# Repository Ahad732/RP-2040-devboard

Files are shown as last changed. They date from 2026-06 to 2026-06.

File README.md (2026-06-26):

# Rp2040 Devboard
I have made a devboard with RP 2040. It has 16 mb storage and its just like a raspberry pi pico but in my design. I had build it off a guide from macondo.I built it to learn hardware. This was my first hardware project for hackclub

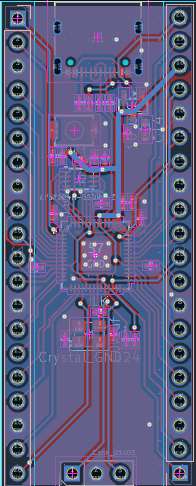
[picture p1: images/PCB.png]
PCB
  
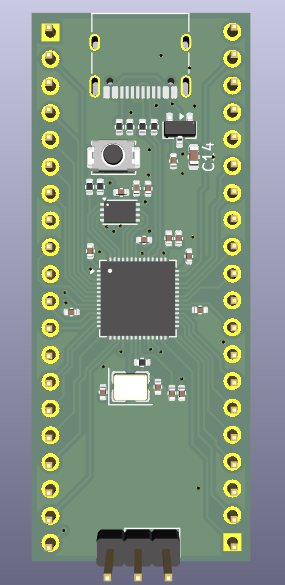
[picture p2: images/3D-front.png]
  
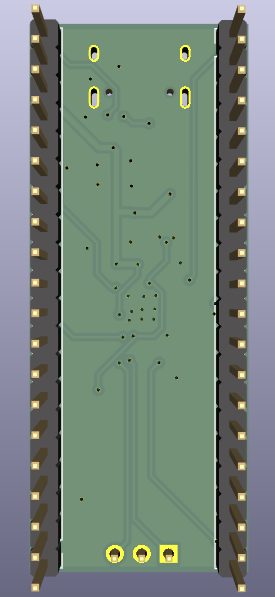
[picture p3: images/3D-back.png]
  
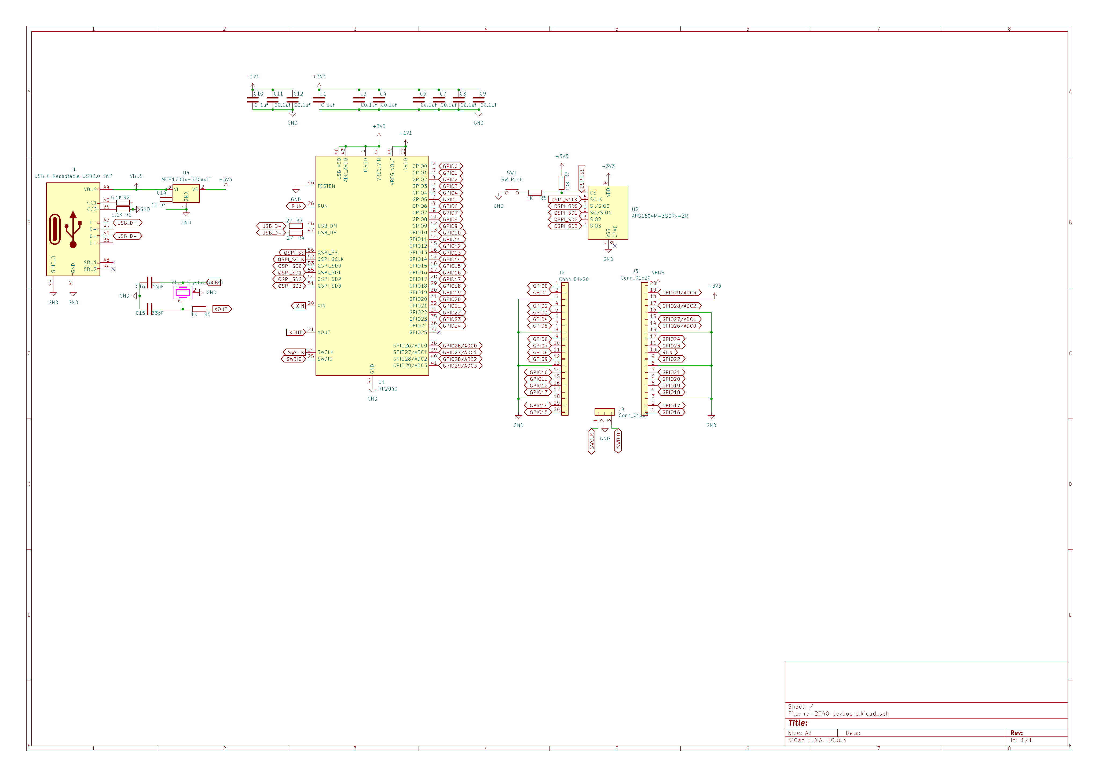
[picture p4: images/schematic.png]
schematic


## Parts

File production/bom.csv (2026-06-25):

Designator | Footprint | Quantity | Value | LCSC Part #
C1_2, C1, C10 | 0402 | 3 | C 1uf
C11, C12, C3, C4, C5, C6, C7, C8, C9_2, C9 | 0402 | 10 | C0.1uf
C14 | 0603 | 1 | 10 uF
C15, C16 | 0402 | 2 | 33pF
J1 | USB_C_Receptacle_XKB_U262-16XN-4BVC11 | 1 | USB_C_Receptacle_USB2.0_16P
J2, J3 | PinHeader_1x20_P2.54mm_Vertical | 2 | Conn_01x20
J4 | PinHeader_1x03_P2.54mm_Vertical | 1 | Conn_01x03
R1, R2 | 0402 | 2 | 5.1K
R3, R4 | 0402 | 2 | 27
R5, R6 | 0402 | 2 | 1K
R7 | 0402 | 1 | 10K
SW1 | SW_Push_SPST_NO_Alps_SKRK | 1 | SW_Push
U1 | QFN-56-1EP_7x7mm_P0.4mm_EP3.2x3.2mm | 1 | RP2040
U2 | Winbond_USON-8-1EP_3x2mm_P0.5mm_EP0.2x1.6mm | 1 | APS1604M-3SQRx-ZR
U4 | SOT-23 | 1 | MCP1700x-330xxTT
Y1 | Crystal_SMD_3225-4Pin_3.2x2.5mm | 1 | Crystal_GND24

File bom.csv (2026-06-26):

Designator | Value | Quantity | Amount | Link
PCB |  | 5 | 2.1 | http://jlcpcb.com/
C1_2, C1, C10 | C 1uf | 50 | 0.24 | https://www.lcsc.com/product-detail/C2929192.html
C11, C12, C3, C4, C5, C6, C7, C8, C9_2, C9 | C0.1uf | 10 | 0.03 | https://www.lcsc.com/product-detail/C237172.html
C14 | 10 uF | 50 | 0.76 | https://www.lcsc.com/product-detail/C105490.html
C15, C16 | 33pF | 100 | 0.14 | https://www.lcsc.com/product-detail/C482484.html
J1 | USB_C_Receptacle_USB2.0_16P | 10 | 0.67 | https://www.lcsc.com/product-detail/C393939.html
J2, J3 | Conn_01x20 | 0 | 0 | dnp
J4 | Conn_01x03 | 0 | 0 | dnp
R1, R2 | 5.1K | 100 | 0.23 | https://www.lcsc.com/product-detail/C2907044.html
R3, R4 | 27 | 100 | 0.24 | https://www.lcsc.com/product-detail/C137753.html
R5, R6 | 1K | 100 | 0.31 | https://www.lcsc.com/product-detail/C2907002.html
R7 | 10K | 100 | 0.14 | https://www.lcsc.com/product-detail/C60490.html
SW1 | SW_Push | 1 | 0.59 | https://www.lcsc.com/product-detail/C221896.html
U1 | RP2040 | 1 | 0.99 | https://www.lcsc.com/product-detail/C2040.html
U2 | APS1604M-3SQRx-ZR | 1 | 2.31 | https://www.lcsc.com/product-detail/C22423595.html
U4 | MCP1700x-330xxTT | 5 | 0.41 | https://www.lcsc.com/product-detail/C41381676.html
Y1 | Crystal_GND24 | 5 | 0.51 | https://www.lcsc.com/product-detail/C9002.html
 |  | PCB Shipping cost | 7.65
 |  | LCSC Shipping cost | 8
 |  | Total | 25.32

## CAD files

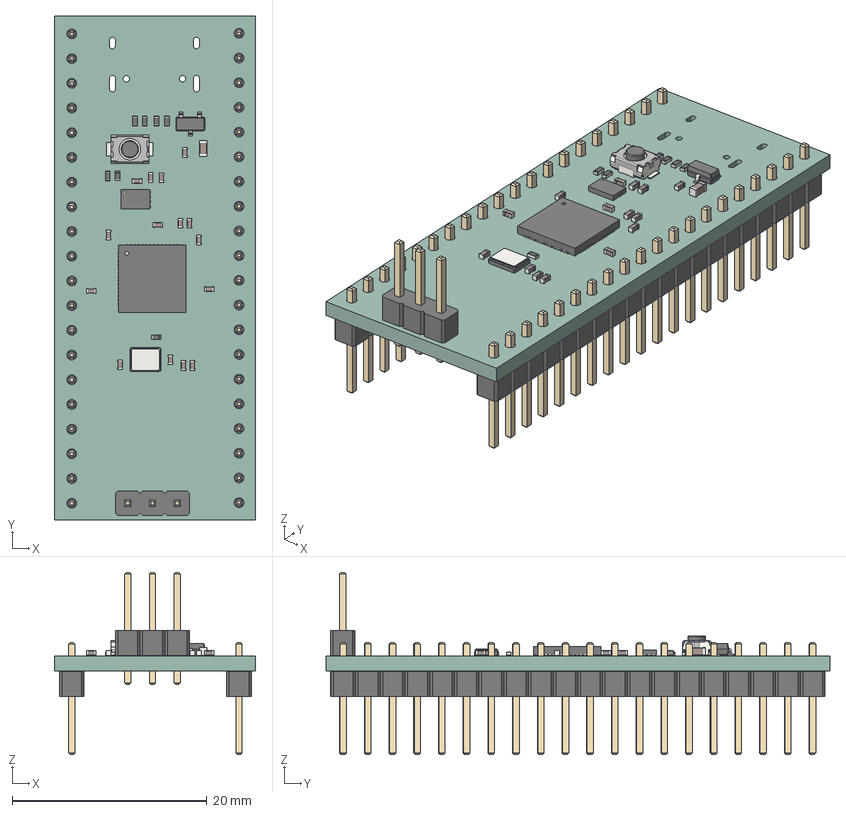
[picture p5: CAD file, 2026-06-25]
CAD/DEVBOARD.step
20.7 x 51.8 x 18.8 mm
C_0402_1005Metric x 15
R_0402_1005Metric x 7
C_0603_1608Metric
SW_Push_SPST_NO_Alps_SKRK
SOT-23
Winbond_USON-8-1EP_3x2mm_P0.5mm_EP0.2x1.6mm
PinHeader_1x03_P254mm_Vertical
QFN-56-1EP_7x7mm_P0.4mm_EP3.2x3.2mm
Crystal_SMD_3225-4Pin_3.2x2.5mm
PinHeader_1x20_P254mm_Vertical x 2
rp-2040 devboard_PCB

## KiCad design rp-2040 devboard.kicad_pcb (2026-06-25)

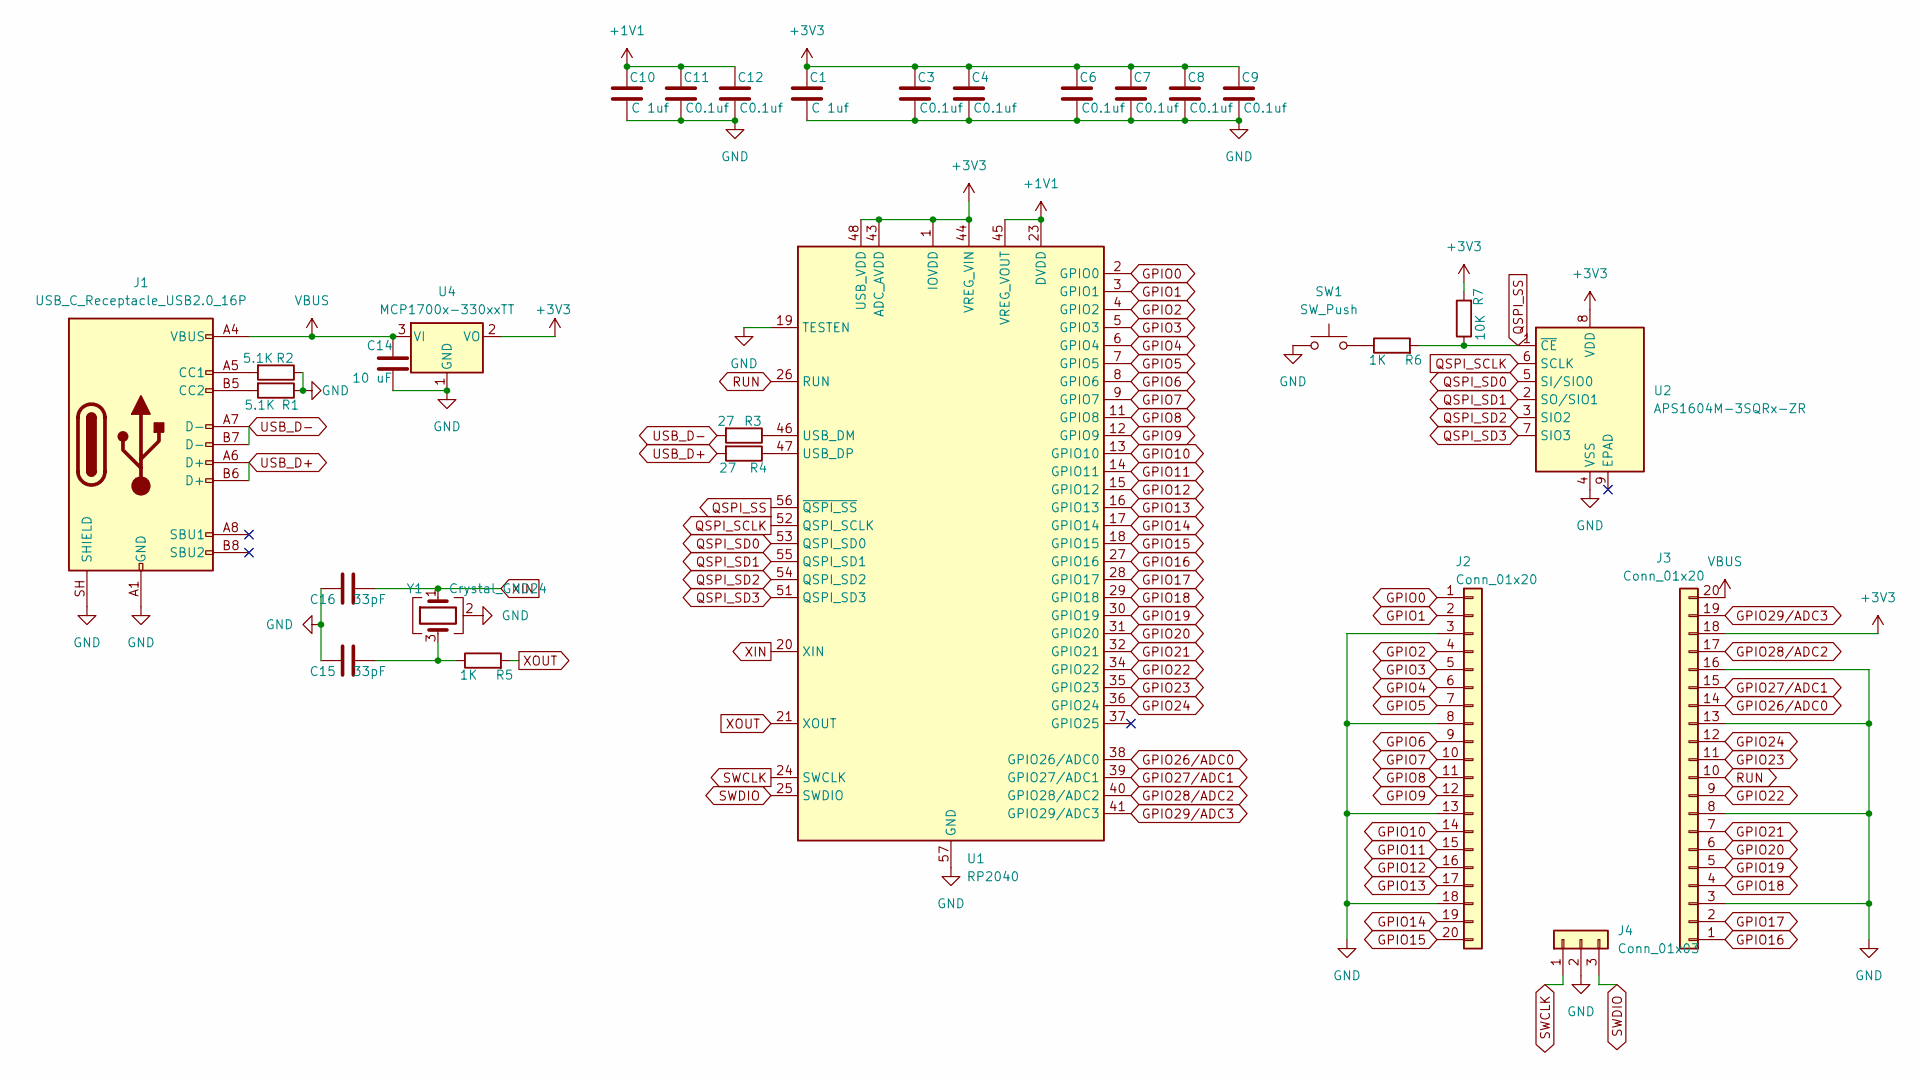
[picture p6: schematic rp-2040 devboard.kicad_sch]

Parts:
C1, C10: C 1uf; C_0402_1005Metric
C3, C4, C6, C7, C8, C9, C11, C12: C0.1uf; C_0402_1005Metric
C14: 10 uF; C_0603_1608Metric
C15, C16: 33pF; C_0402_1005Metric
J1: USB_C_Receptacle_USB2.0_16P; USB_C_Receptacle_XKB_U262-16XN-4BVC11
J2, J3: Conn_01x20; PinHeader_1x20_P2.54mm_Vertical
J4: Conn_01x03; PinHeader_1x03_P2.54mm_Vertical
R1, R2: 5.1K; R_0402_1005Metric
R3, R4: 27; R_0402_1005Metric
R5, R6: 1K; R_0402_1005Metric
R7: 10K; R_0402_1005Metric
SW1: SW_Push; SW_Push_SPST_NO_Alps_SKRK
U1: RP2040; QFN-56-1EP_7x7mm_P0.4mm_EP3.2x3.2mm
U2: APS1604M-3SQRx-ZR; Winbond_USON-8-1EP_3x2mm_P0.5mm_EP0.2x1.6mm
U4: MCP1700x-330xxTT; SOT-23
Y1: Crystal_GND24; Crystal_SMD_3225-4Pin_3.2x2.5mm

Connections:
+1V1: C10.1, C11.1, C12.1, U1.23 (DVDD), U1.45 (VREG_VOUT), U1.50 (DVDD)
+3V3: C1.1, C3.1, C4.1, C6.1, C7.1, C8.1, C9.1, J3.18, R7.2, U1.1 (IOVDD), U1.10 (IOVDD), U1.22 (IOVDD), U1.33 (IOVDD), U1.42 (IOVDD), U1.43 (ADC_AVDD), U1.44 (VREG_VIN), U1.48 (USB_VDD), U1.49 (IOVDD), U2.8 (VDD), U4.2 (VO); also elsewhere on the board
GND: C1.2, C3.2, C4.2, C6.2, C7.2, C8.2, C9.2, C10.2, C11.2, C12.2, C14.2, C15.1, C16.1, J1.A1 (GND), J1.A12 (GND), J1.B1 (GND), J1.B12 (GND), J1.SH (SHIELD), J2.3, J2.8, J2.13, J2.18, J3.3, J3.8, J3.13, J3.16, J4.2, R1.1, R2.1, SW1.1, U1.19 (TESTEN), U1.57 (GND), U2.4 (VSS), U4.1 (GND), Y1.2 (G), Y1.4 (G); also elsewhere on the board
GPIO0: J2.1, U1.2 (GPIO0)
GPIO1: J2.2, U1.3 (GPIO1)
GPIO2: J2.4, U1.4 (GPIO2)
GPIO3: J2.5, U1.5 (GPIO3)
GPIO4: J2.6, U1.6 (GPIO4)
GPIO5: J2.7, U1.7 (GPIO5)
GPIO6: J2.9, U1.8 (GPIO6)
GPIO7: J2.10, U1.9 (GPIO7)
GPIO8: J2.11, U1.11 (GPIO8)
GPIO9: J2.12, U1.12 (GPIO9)
GPIO10: J2.14, U1.13 (GPIO10)
GPIO11: J2.15, U1.14 (GPIO11)
GPIO12: J2.16, U1.15 (GPIO12)
GPIO13: J2.17, U1.16 (GPIO13)
GPIO14: J2.19, U1.17 (GPIO14)
GPIO15: J2.20, U1.18 (GPIO15)
GPIO16: J3.1, U1.27 (GPIO16)
GPIO17: J3.2, U1.28 (GPIO17)
GPIO18: J3.4, U1.29 (GPIO18)
GPIO19: J3.5, U1.30 (GPIO19)
GPIO20: J3.6, U1.31 (GPIO20)
GPIO21: J3.7, U1.32 (GPIO21)
GPIO22: J3.9, U1.34 (GPIO22)
GPIO23: J3.11, U1.35 (GPIO23)
GPIO24: J3.12, U1.36 (GPIO24)
GPIO26/ADC0: J3.14, U1.38 (GPIO26/ADC0)
GPIO27/ADC1: J3.15, U1.39 (GPIO27/ADC1)
GPIO28/ADC2: J3.17, U1.40 (GPIO28/ADC2)
GPIO29/ADC3: J3.19, U1.41 (GPIO29/ADC3)
unnamed: C15.2, R5.1, Y1.3
unnamed: J1.A5 (CC1), R2.2
unnamed: J1.B5 (CC2), R1.2
unnamed: R6.1, SW1.2
unnamed: R3.1, U1.46 (USB_DM)
unnamed: R4.1, U1.47 (USB_DP)
QSPI_SCLK: U1.52 (QSPI_SCLK), U2.6 (SCLK)
QSPI_SD0: U1.53 (QSPI_SD0), U2.5 (SI/SIO0)
QSPI_SD1: U1.55 (QSPI_SD1), U2.2 (SO/SIO1)
QSPI_SD2: U1.54 (QSPI_SD2), U2.3 (SIO2)
QSPI_SD3: U1.51 (QSPI_SD3), U2.7 (SIO3)
QSPI_SS: R6.2, R7.1, U1.56 (~QSPI_SS), U2.1 (~CE)
RUN: J3.10, U1.26 (RUN)
SWCLK: J4.1, U1.24 (SWCLK)
SWDIO: J4.3, U1.25 (SWDIO)
USB_D+: J1.A6 (D+), J1.B6 (D+), R4.2
USB_D-: J1.A7 (D-), J1.B7 (D-), R3.2
VBUS: C14.1, J1.A4 (VBUS), J1.A9 (VBUS), J1.B4 (VBUS), J1.B9 (VBUS), J3.20, U4.3 (VI)
XIN: C16.2, U1.20 (XIN), Y1.1
XOUT: R5.2, U1.21 (XOUT)

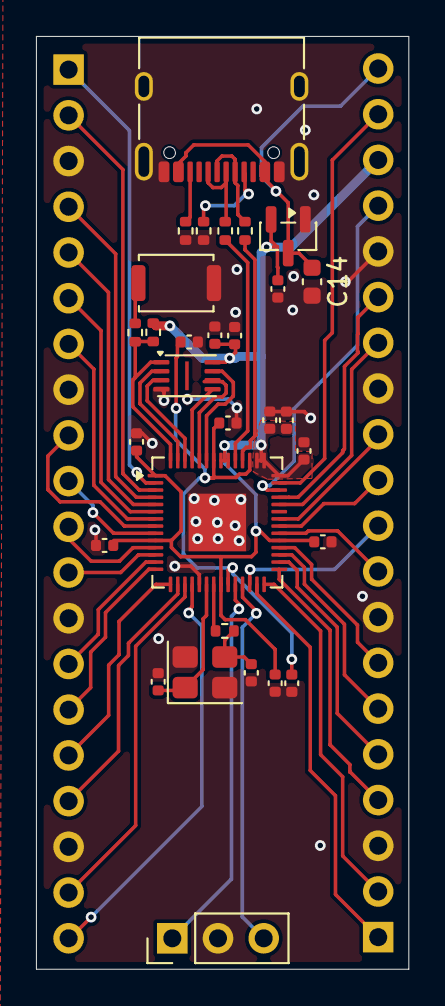
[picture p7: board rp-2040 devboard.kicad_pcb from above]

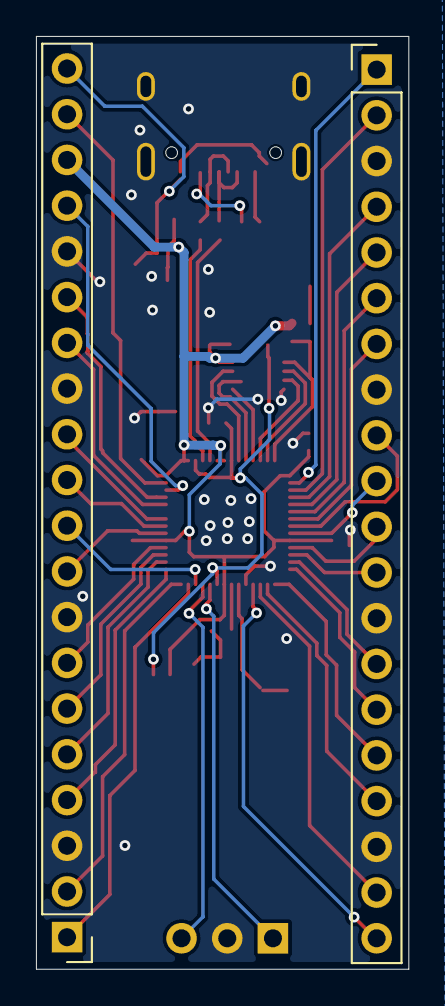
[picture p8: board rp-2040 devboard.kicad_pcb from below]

Board: 2 copper layers, 20.7 x 51.8 mm, 32 parts (2 on the bottom side), 52 nets.

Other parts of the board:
C1#2: C 1uf; C_0402_1005Metric
C5, C9#2: C0.1uf; C_0402_1005Metric

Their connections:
+3V3: C1#2.1, C5.1, C9#2.1; also elsewhere on the board
GND: C1#2.2, C5.2, C9#2.2; also elsewhere on the board

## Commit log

2026-06-25 made the devboard
    [rp-2040 devboard.kicad_pcb, rp-2040 devboard.kicad_sch]
2026-06-25 added images, CAD and gerber files
    [DEVBOARD.step, bom.csv, designators.csv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]
2026-06-26 everything done
    [bom.csv]
